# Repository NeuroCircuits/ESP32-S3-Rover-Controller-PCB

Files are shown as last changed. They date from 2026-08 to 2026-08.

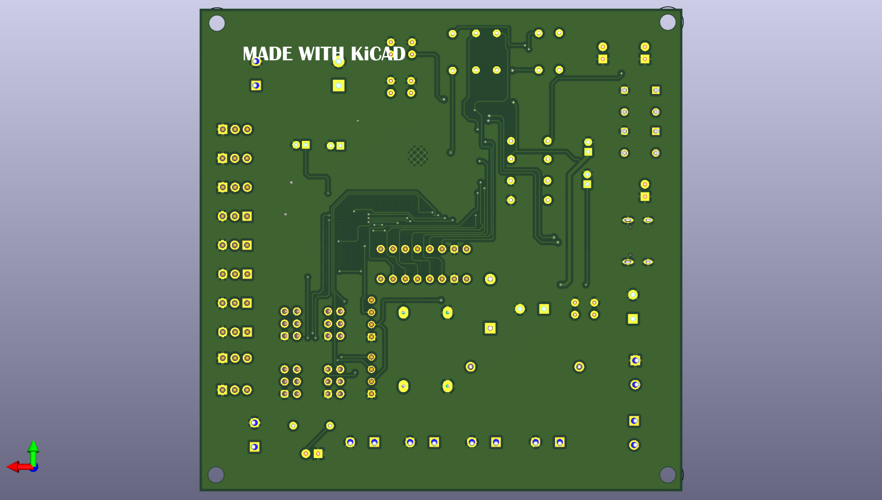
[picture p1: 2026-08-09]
Images/PCB-DESIGN-BACK.png

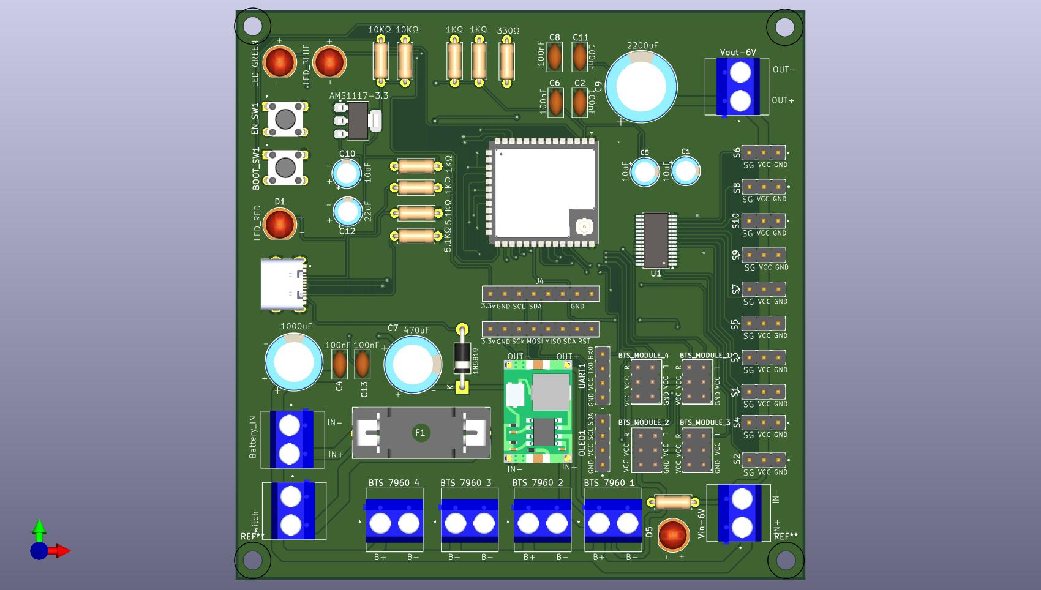
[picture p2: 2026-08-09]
Images/PCB-DESIGN-FRONT.jpg

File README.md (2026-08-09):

# ESP32-S3-Rover-Controller-PCB
Custom ESP32-S3 based controller PCB for a 6-wheel robotic platform, featuring servo control, DC motor drivers, IMU, RFID, USB programming, and dedicated power regulation.

## Overview

This project is a custom controller PCB designed for a mobile robotic platform.

The board is built around the ESP32-S3-WROOM-1U and integrates the main electronics required for controlling the robot, reducing the need for separate wiring and controller boards.

The PCB was designed from schematic to final PCB layout in KiCad, including routing, power distribution, grounding, mounting holes, design-rule checking, and Gerber generation.

## Features

- ESP32-S3-WROOM-1U main controller
- USB Type-C programming interface
- USB-to-UART interface
- Automatic programming / reset circuitry
- PCA9685 16-channel PWM controller
- Support for multiple high-torque servos
- Interfaces for 4 × BTS motor-driver modules
- Control for 6 DC motors
- MPU6050 IMU interface
- RC522 RFID interface
- 3.3 V regulated supply for logic
- 5 V regulated supply
- Dedicated 6 V servo power rail
- High-current power input
- Main power switching
- Fuse protection
- Multiple bulk and decoupling capacitors
- Through-hole mounting holes
- Two-layer PCB
- Custom copper power and GND planes

- ## PCB Design

Designed using KiCad.

The design includes:

- Schematic capture
- Component selection and footprint assignment
- PCB layout
- Power and ground distribution
- Signal routing
- Copper zones
- Mounting holes
- Silkscreen labeling
- Design Rule Check (DRC)
- Gerber generation

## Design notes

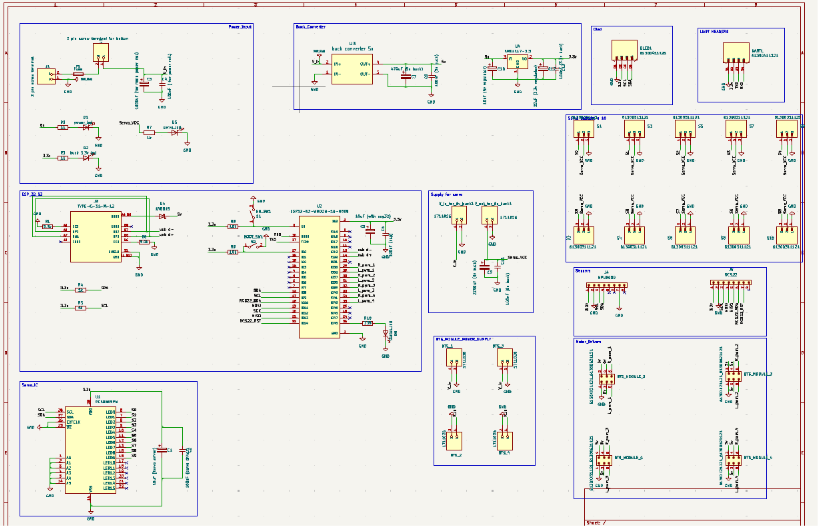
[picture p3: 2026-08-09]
Images/Schemetic.png

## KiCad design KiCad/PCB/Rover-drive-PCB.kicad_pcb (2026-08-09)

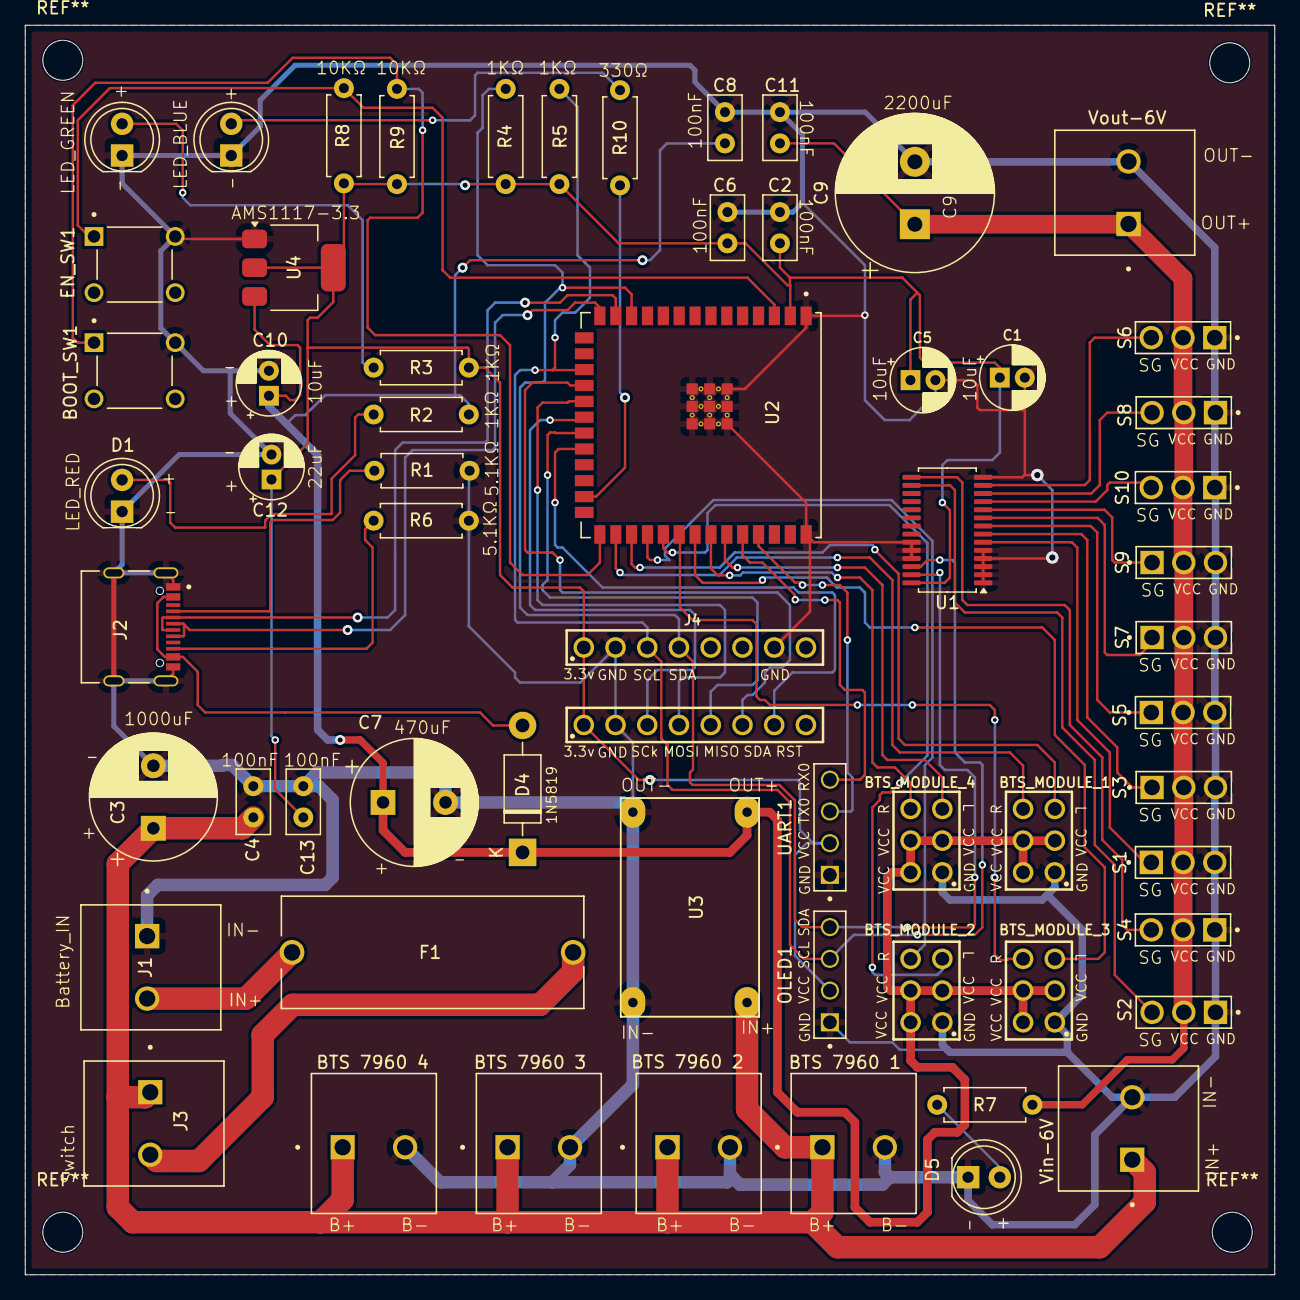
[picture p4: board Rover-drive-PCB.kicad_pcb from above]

Board: 2 copper layers, 100.0 x 100.0 mm, 62 parts (0 on the bottom side), 46 nets.

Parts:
BOOT_SW1: S2; 4_pin_tacticle_push_button
BTS 7960 1, BTS 7960 2, BTS 7960 3, BTS 7960 4: 1711026; PHOENIX_1711026
BTS_MODULE_1, BTS_MODULE_2, BTS_MODULE_3, BTS_MODULE_4: 6130XX21121_61300621121; 61300621121
C1: 10uF (Servo driver); CP_Radial_D5.0mm_P2.00mm
C2: 100nF (servo driver); C_Disc_D5.0mm_W2.5mm_P2.50mm
C3: 1000uF (for main power rail); CP_Radial_D10.0mm_P5.00mm
C4: 100nF ( for power rail); C_Disc_D5.0mm_W2.5mm_P2.50mm
C5: 10uF (with esp32); CP_Radial_D5.0mm_P2.00mm
C6: 100nF (esp); C_Disc_D5.0mm_W2.5mm_P2.50mm
C7: 470uF (5v buck); CP_Radial_D10.0mm_P5.00mm
C8: 100nF (5v buck); C_Disc_D5.0mm_W2.5mm_P2.50mm
C9: 2200uF (6v buck); CP_Radial_D12.5mm_P5.00mm
C10: 10uF (5v regulator); CP_Radial_D5.0mm_P2.00mm
C11: 100nF (6v buck); C_Disc_D5.0mm_W2.5mm_P2.50mm
C12: 22uF (3.3v regulator); CP_Radial_D5.0mm_P2.00mm
C13: 100nF (3.3v buck); C_Disc_D5.0mm_W2.5mm_P2.50mm
D1: power_led; LED_D5.0mm
D2: buck 3.3v led; LED_D5.0mm
D4: 1N5819; D_DO-41_SOD81_P10.16mm_Horizontal
D5: servo_led; LED_D5.0mm
D6: status_led; LED_D5.0mm
EN_SW1: S1; 4_pin_tacticle_push_button
F1: Fuse; FUSE_4628
J1: 2 pin screw terminal; PHOENIX_1711026
J2: TYPE-C-31-M-12; HRO_TYPE-C-31-M-12
J3: 2 pin screw terminal for button; PHOENIX_1711026
J4: MPU6050; 61300811121
J5: RC522; 61300811121
OLED1: 61300411121; WURTH_61300411121
R1, R6: 5.1k; R_Axial_DIN0207_L6.3mm_D2.5mm_P7.62mm_Horizontal
R2, R3, R4, R5, R7: 1k; R_Axial_DIN0207_L6.3mm_D2.5mm_P7.62mm_Horizontal
R8, R9: 10k; R_Axial_DIN0207_L6.3mm_D2.5mm_P7.62mm_Horizontal
R10: 330; R_Axial_DIN0207_L6.3mm_D2.5mm_P7.62mm_Horizontal
S1, S2, S3, S4, S5, S6, S7, S8, S9, S10: 61300311121; 3_pin_male_header
U1: PCA9685PW; TSSOP-28_4.4x9.7mm_P0.65mm
U2: ESP32-S3-WROOM-1U-N8R8; XCVR_ESP32-S3-WROOM-1U-N8R8
U3: buck converter 5v; Mini360_step-down (3)
U4: AMS1117-3.3; SOT-223-3_TabPin2
UART1: 61300411121; WURTH_61300411121
Vin-6V: 1711026; PHOENIX_1711026
Vout-6V: 1711026; PHOENIX_1711026

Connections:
/3.3v: C1.1, C2.1, C5.1, C6.1, C12.1, C13.1, J4.1, J5.1, OLED1.02, R3.1, R4.1, R5.1, R8.1, R9.2, U1.28 (VDD), U2.2 (3V3), U4.2 (VO), UART1.02
/5v: BTS_MODULE_1.2, BTS_MODULE_1.3, BTS_MODULE_1.4, BTS_MODULE_2.2, BTS_MODULE_2.3, BTS_MODULE_2.4, BTS_MODULE_3.2, BTS_MODULE_3.3, BTS_MODULE_3.4, BTS_MODULE_4.2, BTS_MODULE_4.3, BTS_MODULE_4.4, C7.1, C8.1, C10.1, D4.1 (K), R2.1, U3.4 (OUT+), U4.3 (VI)
/L_pwm_1: BTS_MODULE_4.5, U2.29 (IO36)
/L_pwm_2: BTS_MODULE_3.5, U2.31 (IO38)
/L_pwm_3: BTS_MODULE_2.5, U2.33 (IO40)
/L_pwm_4: BTS_MODULE_1.5, U2.35 (IO42)
/MISO: J5.5, U2.21 (IO13)
/MOSI: J5.4, U2.19 (IO11)
/RC522_RST: J5.7, U2.22 (IO14)
/RC522_SDA: J5.6, U2.18 (IO10)
/RX0: U2.36 (RXD0), UART1.04
/R_pwm_1: BTS_MODULE_4.6, U2.28 (IO35)
/R_pwm_2: BTS_MODULE_3.6, U2.30 (IO37)
/R_pwm_3: BTS_MODULE_2.6, U2.32 (IO39)
/R_pwm_4: BTS_MODULE_1.6, U2.34 (IO41)
/S0: S1.1, U1.6 (LED0)
/S1: S3.1, U1.7 (LED1)
/S2: S5.1, U1.8 (LED2)
/S3: S7.1, U1.9 (LED3)
/S4: S9.1, U1.10 (LED4)
/S5: S10.3, U1.11 (LED5)
/S6: S8.3, U1.12 (LED6)
/S7: S6.3, U1.13 (LED7)
/S8: S4.3, U1.15 (LED8)
/S9: S2.3, U1.16 (LED9)
/SCK: J5.3, U2.20 (IO12)
/SCL: J4.3, OLED1.03, R5.2, U1.26 (SCL), U2.17 (IO9)
/SDA: J4.4, OLED1.04, R4.2, U1.27 (SDA), U2.12 (IO8)
/Servo_VCC: C9.1, C11.1, R7.1, S1.2, S2.2, S3.2, S4.2, S5.2, S6.2, S7.2, S8.2, S9.2, S10.2, Vout-6V.1
/TX0: U2.37 (TXD0), UART1.03
/V_in: BTS 7960 1.1, BTS 7960 2.1, BTS 7960 3.1, BTS 7960 4.1, C3.1, C4.1, J3.1, U3.2 (IN+), Vin-6V.1
/usb d+: J2.A6 (DP1), J2.B6 (DP2), U2.14 (IO20)
/usb d-: J2.A7 (DN1), J2.B7 (DN2), U2.13 (IO19)
GND: BOOT_SW1.2 (B), BTS 7960 1.2, BTS 7960 2.2, BTS 7960 3.2, BTS 7960 4.2, BTS_MODULE_1.1, BTS_MODULE_2.1, BTS_MODULE_3.1, BTS_MODULE_4.1, C1.2, C2.2, C3.2, C4.2, C5.2, C6.2, C7.2, C8.2, C9.2, C10.2, C11.2, C12.2, C13.2, D1.1 (K), D2.1 (K), D5.1 (K), D6.1 (K), EN_SW1.2 (B), J1.1, J2.A1_B12 (GND), J2.B1_A12 (GND), J2.S1 (SHIELD), J2.S2 (SHIELD), J2.S3 (SHIELD), J2.S4 (SHIELD), J4.2, J4.7, J5.2, OLED1.01, R1.1, R6.2, S1.3, S2.1, S3.3, S4.1, S5.3, S6.1, S7.3, S8.1, S9.3, S10.1, U1.1 (A0), U1.2 (A1), U1.3 (A2), U1.4 (A3), U1.5 (A4), U1.14 (VSS), U1.23 (~OE), U1.24 (A5), U1.25 (EXTCLK), U2.1 (GND), U2.40 (GND), U2.41_1 (GND), U2.41_2 (GND), U2.41_3 (GND), U2.41_4 (GND), U2.41_5 (GND), U2.41_6 (GND), U2.41_7 (GND), U2.41_8 (GND), U2.41_9 (GND), U2.41_10, U2.41_11, U2.41_12, U2.41_13, U2.41_14, U2.41_15, U2.41_16, U2.41_17, U2.41_18, U2.41_19, U2.41_20, U2.41_21, U3.1 (IN-), U3.3 (OUT-), U4.1 (GND), UART1.01, Vin-6V.2, Vout-6V.2
unnamed: BOOT_SW1.1 (A), R9.1, U2.27 (IO0)
unnamed: D1.2 (A), R2.2
unnamed: D2.2 (A), R3.2
unnamed: D5.2 (A), R7.2
unnamed: D6.2 (A), R10.2
unnamed: EN_SW1.1 (A), R8.2, U2.3 (EN)
unnamed: F1.1, J1.2
unnamed: F1.2, J3.2
unnamed: J2.A5 (CC1), R1.2
unnamed: J2.B5 (CC2), R6.1
unnamed: R10.1, U2.25 (IO48)
VBUS: D4.2 (A), J2.A4_B9 (VBUS), J2.B4_A9 (VBUS)

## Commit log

2026-08-09 Enhance README with PCB design details
    Added a brief description of the PCB design.
2026-08-09 Create Schematic
